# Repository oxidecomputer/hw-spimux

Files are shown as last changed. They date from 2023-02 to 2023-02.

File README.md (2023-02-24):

# hw-spimux




PMOD Quad SPI flash mux debug board
Breaks out the Gimletlet QSPI port to a MT25QU256ABA8E12 Flash memory IC.
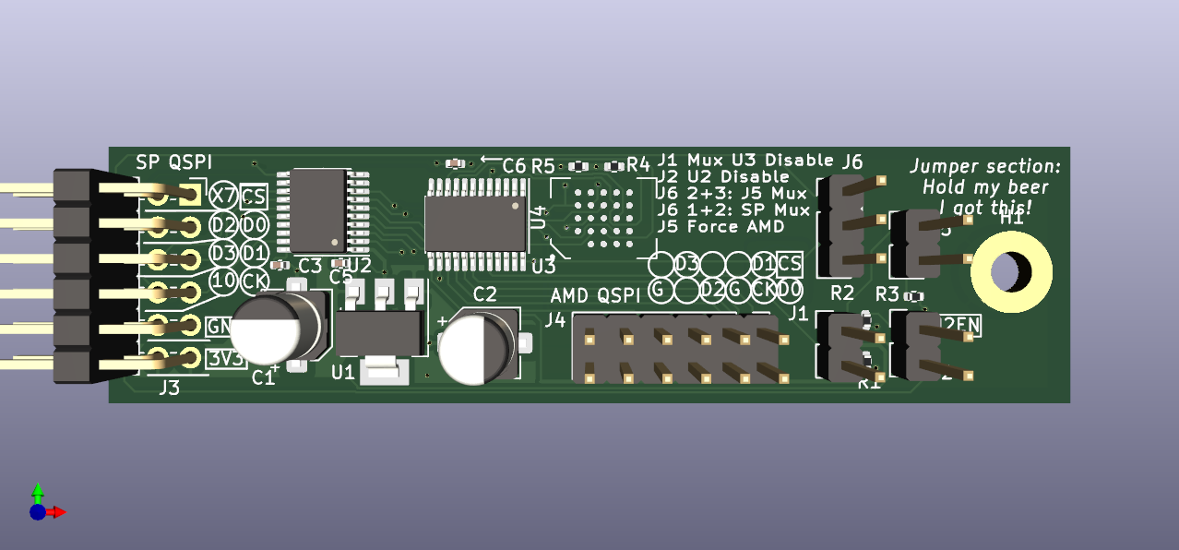
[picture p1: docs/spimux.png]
spi_mux_render


# Model Change Notices
We use Model Change Notices (MCNs) to track rework made in between CAD updates 
andboard spins.
These are preserved in this repo for historical and reference reasons even
after the CAD has been updated.

# Status
The CAD represents what was built without the MCN(s) applied.

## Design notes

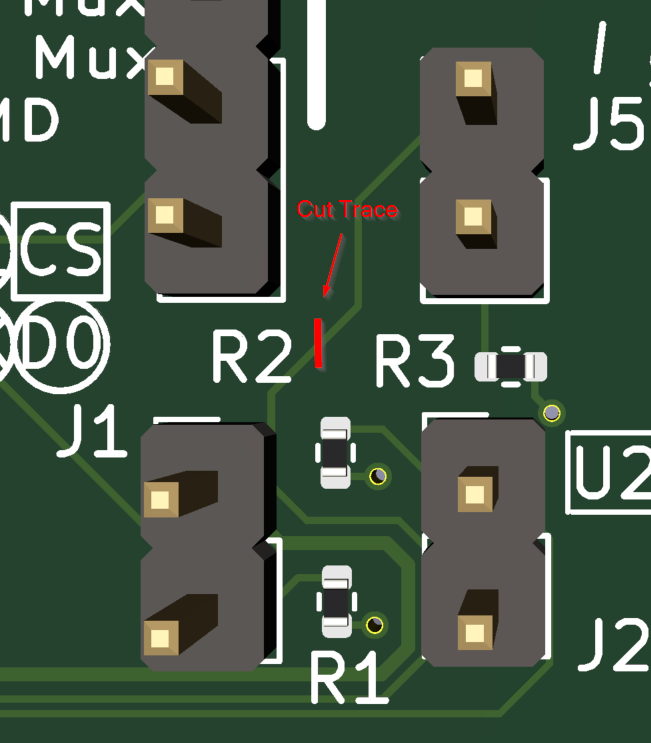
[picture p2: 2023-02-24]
MCNs/2E1/jumper_topside.png

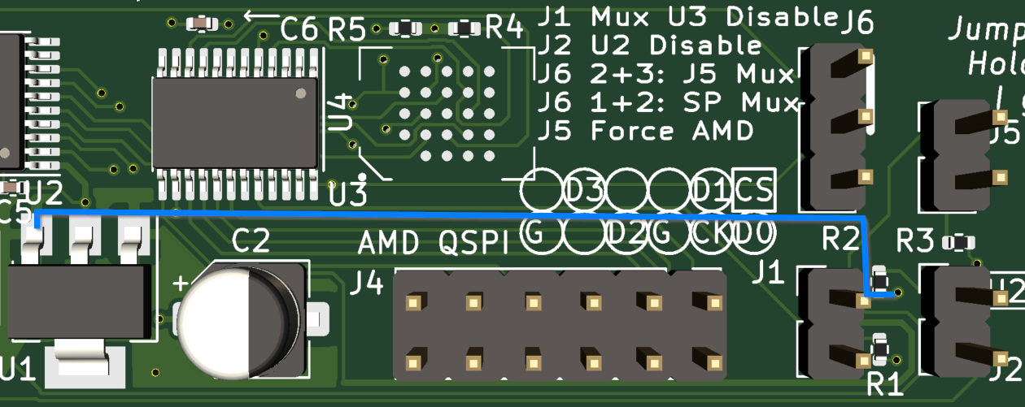
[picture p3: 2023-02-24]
MCNs/2E1/topside_jumper2.png

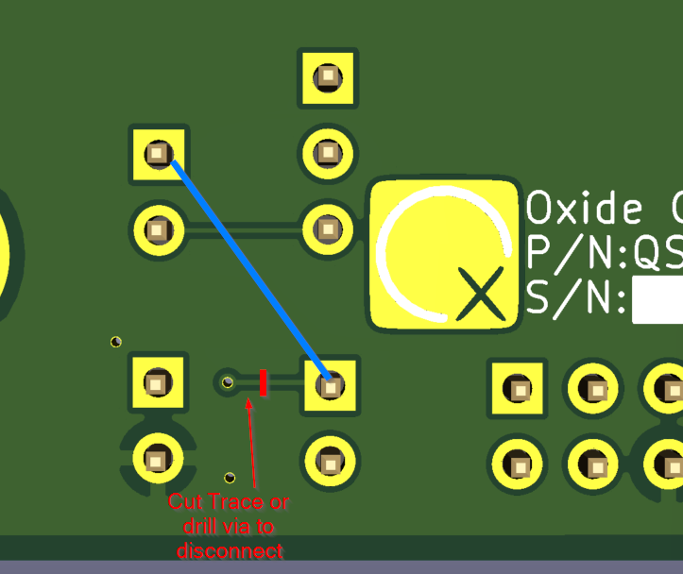
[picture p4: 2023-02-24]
MCNs/2E1/bottom-side_jumper.png

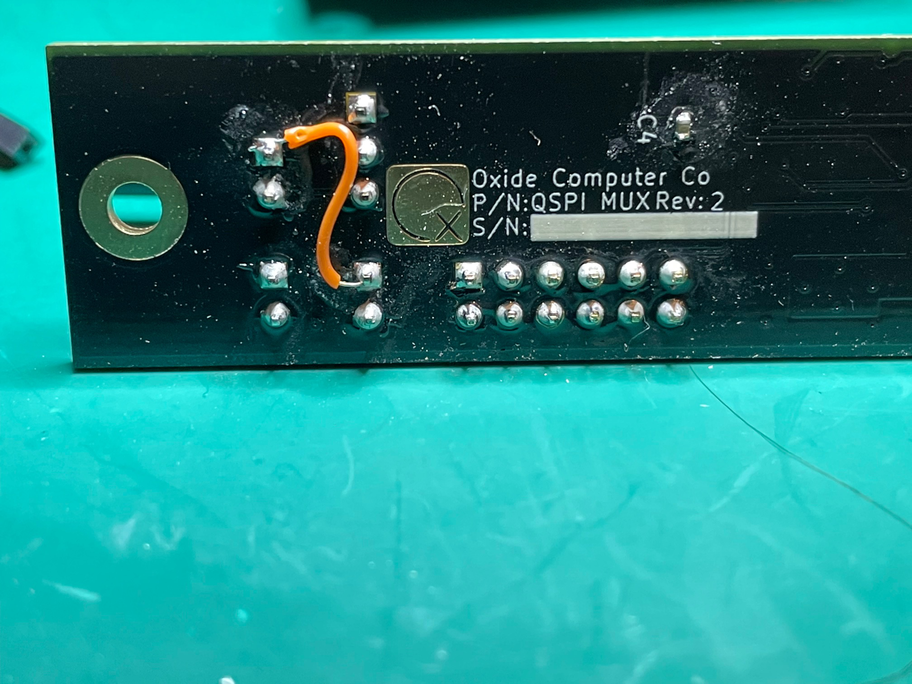
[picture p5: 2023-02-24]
MCNs/2E1/bottom_finished.jpg

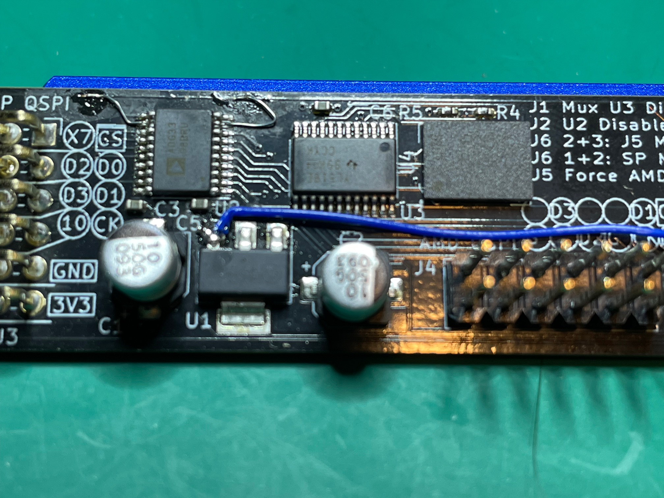
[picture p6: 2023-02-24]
MCNs/2E1/top_finished.jpg

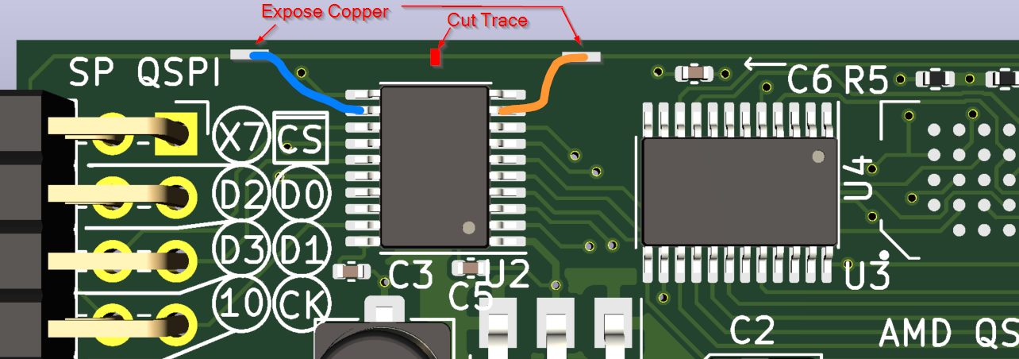
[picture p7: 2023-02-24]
MCNs/2E1/enable_level_trans.png

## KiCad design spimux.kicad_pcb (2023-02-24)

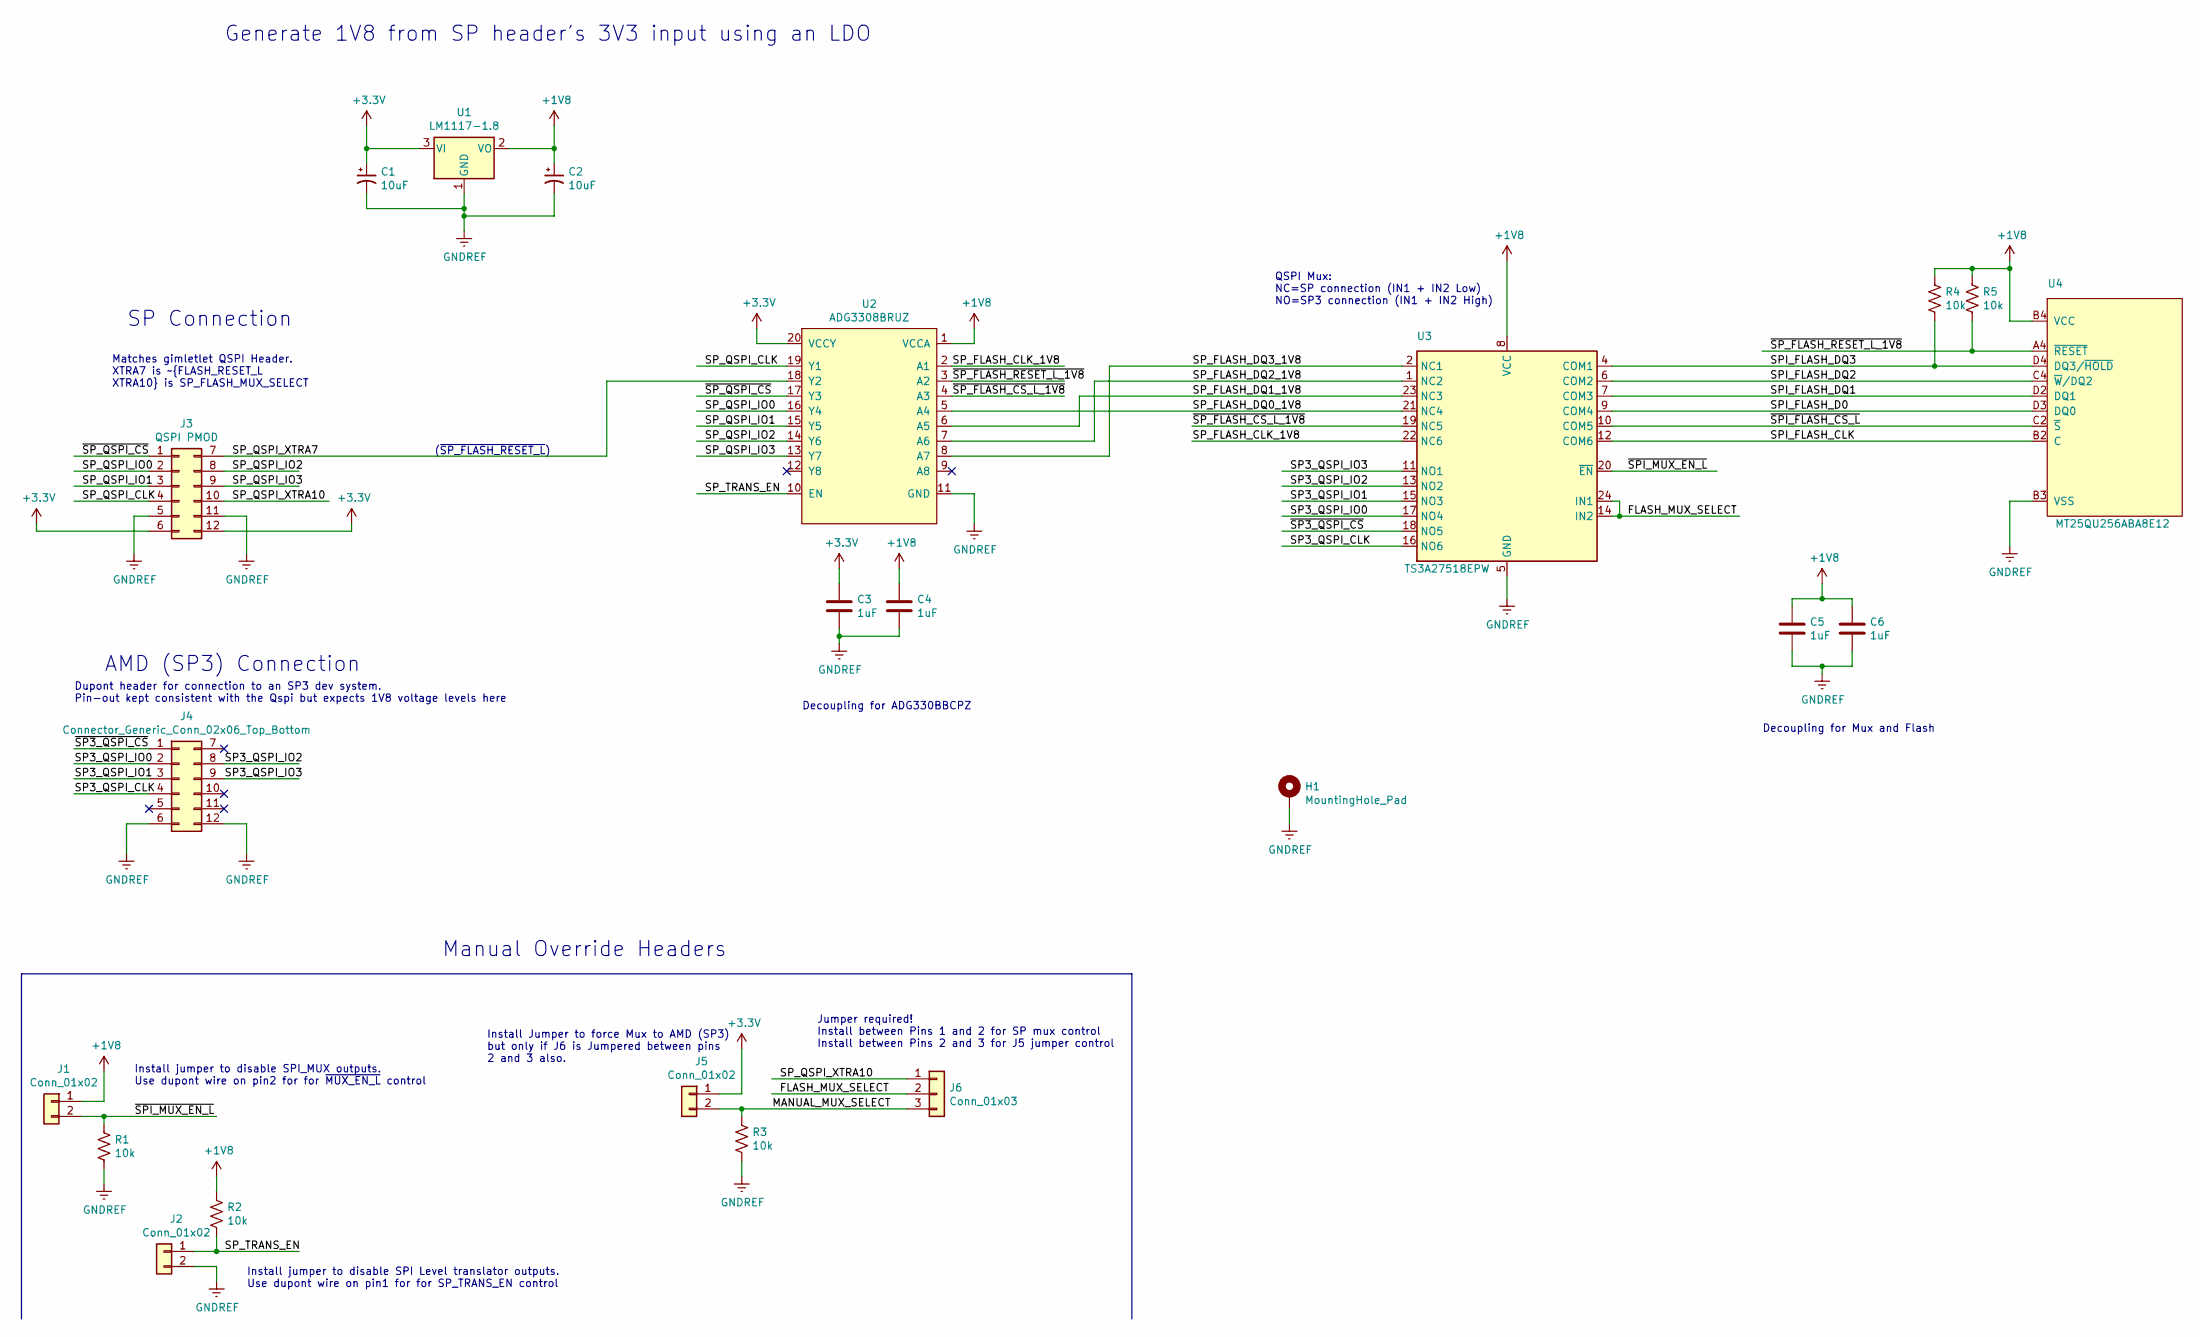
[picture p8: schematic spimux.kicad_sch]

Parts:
C1, C2: 10uF; CP_Elec_5x5.3; MPN EDK106M050A9DAA
C3, C4, C5, C6: 1uF; C_0402_1005Metric
H1: MountingHole_Pad; MountingHole_3.2mm_M3_Pad
J1, J2, J5: Conn_01x02; PinHeader_1x02_P2.54mm_Vertical; MPN PRPC024SAAN-RC
J3: QSPI PMOD; PMOD_12pin_peripheral_horizontal
J4: Connector_Generic_Conn_02x06_Top_Bottom; PinHeader_2x06_P2.54mm_Vertical
J6: Conn_01x03; PinHeader_1x03_P2.54mm_Vertical; MPN PRPC024SAAN-RC
R1, R2, R3, R4, R5: 10k; R_0402_1005Metric
U1: LM1117-1.8; SOT-223; MPN LM1117MPX-18NOPB
U2: ADG3308BRUZ; TSSOP-20_4.4x6.5mm_P0.65mm
U3: TS3A27518EPW; TSSOP-24_4.4x7.8mm_P0.65mm; MPN TS3A27518EPWR
U4: MT25QU256ABA8E12; BGA-25_5x5_6.0x8.0mm

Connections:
+1V8: C2.1, C4.1, C5.1, C6.1, J1.1, R2.1, R4.1, R5.1, U1.2 (VO), U2.1 (VCCA), U3.8 (VCC), U4.B4 (VCC)
+3V3: C1.1, C3.1, J3.6, J3.12, J5.1, U1.3 (VI), U2.20 (VCCY)
/FLASH_MUX_SELECT: J6.2, U3.14 (IN2), U3.24 (IN1)
/MANUAL_MUX_SELECT: J5.2, J6.3, R3.1
/SP3_QSPI_CLK: J4.4, U3.16 (NO6)
/SP3_QSPI_IO0: J4.2, U3.17 (NO4)
/SP3_QSPI_IO1: J4.3, U3.15 (NO3)
/SP3_QSPI_IO2: J4.8, U3.13 (NO2)
/SP3_QSPI_IO3: J4.9, U3.11 (NO1)
/SPI_FLASH_CLK: U3.12 (COM6), U4.B2 (C)
/SPI_FLASH_D0: U3.9 (COM4), U4.D3 (DQ0)
/SPI_FLASH_DQ1: U3.7 (COM3), U4.D2 (DQ1)
/SPI_FLASH_DQ2: U3.6 (COM2), U4.C4 (~W/DQ2)
/SPI_FLASH_DQ3: R4.2, U3.4 (COM1), U4.D4 (DQ3/~HOLD)
/SP_FLASH_CLK_1V8: U2.2 (A1), U3.22 (NC6)
/SP_FLASH_DQ0_1V8: U2.5 (A4), U3.21 (NC4)
/SP_FLASH_DQ1_1V8: U2.6 (A5), U3.23 (NC3)
/SP_FLASH_DQ2_1V8: U2.7 (A6), U3.1 (NC2)
/SP_FLASH_DQ3_1V8: U2.8 (A7), U3.2 (NC1)
/SP_QSPI_CLK: J3.4, U2.19 (Y1)
/SP_QSPI_IO0: J3.2, U2.16 (Y4)
/SP_QSPI_IO1: J3.3, U2.15 (Y5)
/SP_QSPI_IO2: J3.8, U2.14 (Y6)
/SP_QSPI_IO3: J3.9, U2.13 (Y7)
/SP_QSPI_XTRA7: J3.7, U2.18 (Y2)
/SP_QSPI_XTRA10: J3.10, J6.1
/SP_TRANS_EN: J2.1, R2.2, U2.10 (EN)
/~SP3_QSPI_CS: J4.1, U3.18 (NO5)
/~SPI_FLASH_CS_L: U3.10 (COM5), U4.C2 (~S)
/~SPI_MUX_EN_L: J1.2, R1.1, U3.20 (~EN)
/~SP_FLASH_CS_L_1V8: U2.4 (A3), U3.19 (NC5)
/~SP_FLASH_RESET_L_1V8: R5.2, U2.3 (A2), U4.A4 (~RESET)
/~SP_QSPI_CS: J3.1, U2.17 (Y3)
GNDREF: C1.2, C2.2, C3.2, C4.2, C5.2, C6.2, H1.1, J2.2, J3.5, J3.11, J4.6, J4.12, R1.2, R3.2, U1.1 (GND), U2.11 (GND), U3.5 (GND), U4.B3 (VSS)

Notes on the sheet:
(~{SP_FLASH_RESET_L})
Dupont header for connection to an SP3 dev system. Pin-out kept consistent with the Qspi but expects 1V8 voltage levels here
Matches gimletlet QSPI Header. XTRA7 is ~{FLASH_RESET_L XTRA10} is SP_FLASH_MUX_SELECT
Manual Override Headers
Jumper required! Install between Pins 1 and 2 for SP mux control Install between Pins 2 and 3 for J5 jumper control
QSPI Mux: NC=SP connection (IN1 + IN2 Low) NO=SP3 connection (IN1 + IN2 High)
Install jumper to disable SPI_MUX outputs. Use dupont wire on pin2 for for ~{MUX_EN_L} control
Install Jumper to force Mux to AMD (SP3) but only if J6 is Jumpered between pins 2 and 3 also.
SP Connection
Decoupling for Mux and Flash
AMD (SP3) Connection
Decoupling for ADG330BBCPZ
Install jumper to disable SPI Level translator outputs. Use dupont wire on pin1 for for SP_TRANS_EN control
Generate 1V8 from SP header's 3V3 input using an LDO

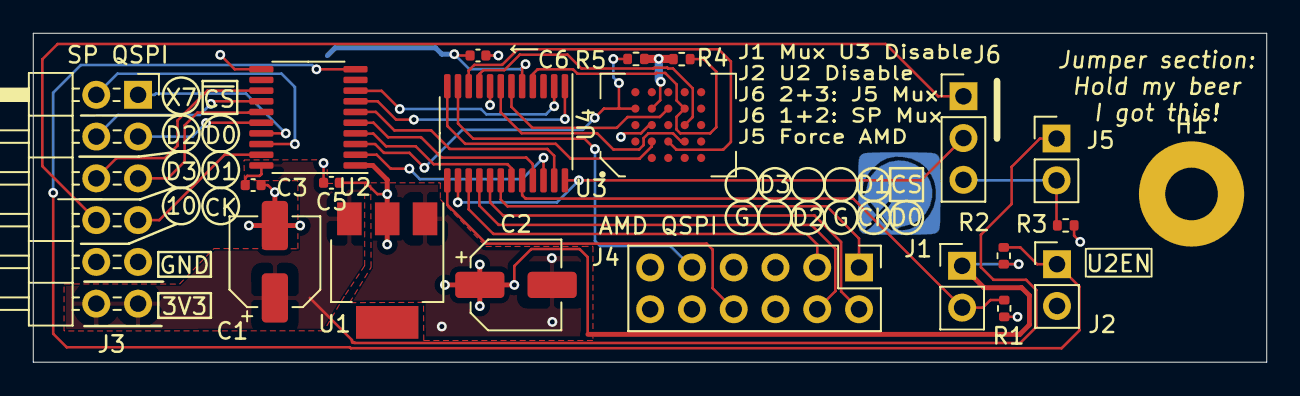
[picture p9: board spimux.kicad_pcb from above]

Board: 2 copper layers, 75.0 x 20.0 mm, 22 parts (1 on the bottom side), 34 nets.
